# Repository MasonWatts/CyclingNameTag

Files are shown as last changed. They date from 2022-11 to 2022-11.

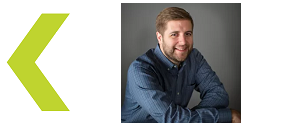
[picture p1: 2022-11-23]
Resources/Sample3.bmp

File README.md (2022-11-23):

# Overview
A fun DIY name tag I made for attending conferences and recruiting events. It uses an Adafruit eInk display, Adafruit Feather 328P MCU, and SD card to rotate through images. I made a few image slides that have company logo, name, picture, etc. for use as a name tag, but it could also work for other applications. With my chosen battery, it lasted about 12 hours on a full charge, which was plenty for a full day event.

# Setup
Parts List:
1. Adafruit Feather 328P (P/N 3458), w/ headers soldered on
2. Adafruit 2.9" Grayscale eInk display (P/N 4777)
3. MicroSD card
3. (Optional) Adafruit Lithium Ion Battery of your choice (I used P/N 3898, 400mAh)
4. (Optional) 3D printed enclosure (STL file is in repo)
5. (Optional) Four M2x20 screws, four M2 nuts to secure electronics to 3D printed enclosure
6. (Optional) Chip clip or other scrappy way to connect it to your shirt!

Process:
1. Solder male headers to MCU.
2. Load images on microSD card, naming files such that they are in desired order, and insert it into eInk display's card expansion slot.
3. Gently seat MCU's male headers into display's female headers.
4. If you're using a battery, attach it to the MCU's JST connector.
5. If you're using my 3D printed enclosure, rig up your attachment method (I used a chip clip I have lying around), then seat the display/MCU so that USB ports match up with corresponding cutouts and secure down with M3 screws/nuts.
6. Connect MCU to PC, fire up Arduino IDE, and upload the sketch. (If you have trouble setting up Arduino IDE for the MCU, see [Adafruit's guide](https://learn.adafruit.com/adafruit-feather-328p-atmega328-atmega328p)).
7. Watch your images scroll by!

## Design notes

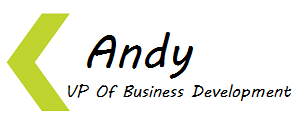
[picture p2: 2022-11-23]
Resources/Sample2.bmp

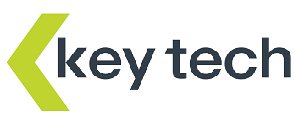
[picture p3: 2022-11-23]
Resources/Sample1.bmp

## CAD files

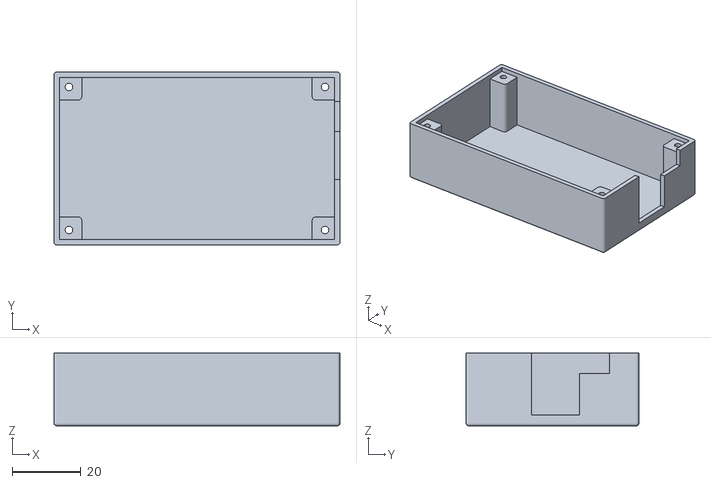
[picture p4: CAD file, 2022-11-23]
Enclosure Bottom.stl
83.2 x 50.3 x 21.2

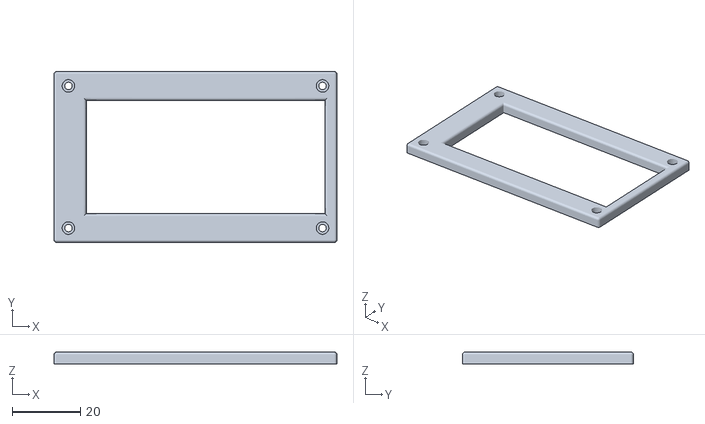
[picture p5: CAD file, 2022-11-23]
Enclosure Faceplate.stl
83.2 x 50.3 x 3.50

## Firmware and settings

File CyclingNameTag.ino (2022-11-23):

/*
 * Written by Mason Watts, Dec 1 2021
 * Basic code for a dynamic name tag. 
 * Uses a Adafruit Feather 328P (Product #3458) and Adafruit 2.9" Grayscale eInk Display FeatherWing.
 * Iterates over images (.bmp) in the root directory of the loaded SD card, waiting a short period before displaying the next image.
 * This display supports a maximum image resolution of 296 x 128.
 */

#include <Adafruit_GFX.h>
#include "Adafruit_ThinkInk.h"
#include <SdFat.h>
#include <Adafruit_ImageReader_EPD.h>

// Pin assignments - 328P
#define SD_CS        5
#define SRAM_CS      6
#define EPD_CS       9
#define EPD_DC      10  
#define EPD_RESET   -1
#define EPD_BUSY    -1

// It takes approx. 5 seconds to read from SD card and display, so real time between images is 5s plus this value
#define IMAGE_DWELL_TIME_MS 2000

// Global resources
ThinkInk_290_Grayscale4_T5 display(EPD_DC, EPD_RESET, EPD_CS, SRAM_CS, EPD_BUSY);
SdFat sd;
Adafruit_ImageReader_EPD reader(sd);

void setup(void) 
{
    // Start debug Serial
    Serial.begin(9600);
    // Set up E-Ink display
    display.begin();
    display.clearBuffer();
    display.display();
    // Set up SD card
    if(!sd.begin(SD_CS, SD_SCK_MHZ(10))) 
    {
      Serial.println(F("SD begin() failed"));
      display.println("failed!");
      display.display();
      while(true);
    }
    Serial.println("Setup Complete");
}

void loop() 
{
    ImageReturnCode stat;
    SdFile root;
    SdFile file;

    // Open SD Card root
    if (!root.open("/")) 
    {
        sd.errorHalt("Open root failed");
    }

    // Iterate over all SD card files in root
    while (file.openNext(&root, O_RDONLY)) 
    {
        // Skip directories
        if (file.isDir()) 
        {
            file.close();
            continue;
        }

        // Save a local copy of file's name (making sure to close it)
        char fileName[80] = {0};
        file.getName(fileName, 80);
        Serial.print("Displaying file ");
        Serial.println(fileName);
        file.close();

        // Use Adafruit ImageReader class to display the current image file
        display.clearBuffer();
        stat = reader.drawBMP(fileName, display, 0, 0);
        Serial.print("Display result: ");
        reader.printStatus(stat);  
        display.display();

        // Dwell a bit on the loaded image before the next
        delay(IMAGE_DWELL_TIME_MS);
    }

    // Print any pending errors from the file system, then repeat!
    if (root.getError()) 
    {
        // No action needed
    } 
    else 
    {
        Serial.println("Finished all files, starting over!");
        Serial.println("=============================================");
    }
}

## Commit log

2022-11-23 Added sample image files
2022-11-23 Added STL files for enclosure
    [Enclosure Bottom.stl, Enclosure Faceplate.stl]
